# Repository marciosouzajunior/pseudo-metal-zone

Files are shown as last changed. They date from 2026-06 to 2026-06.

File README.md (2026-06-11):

# Pseudo Metal Zone

Pedal de distorção/fuzz pesado baseado em **RC4558/JRC4558**, desenvolvido em protoboard e depois convertido para **PCB V1 em KiCad**.

A ideia é chegar em uma distorção agressiva para baixo/guitarra, inspirada de forma conceitual no Boss Metal Zone e em timbres de hard rock/nu metal, mas com um circuito simples, compreendido estágio por estágio, usando componentes THT e um único CI dual op-amp.

## Objetivo sonoro

- Distorção pesada para baixo/guitarra.
- Mais definida que fuzz puro.
- Grave presente, mas sem embolar demais.
- Agudos controlados, reduzindo fizz/chiado.
- Funcionamento com alimentação simples de 9 V.
- Projeto didático, fácil de modificar e medir.

## Arquitetura do circuito

Fluxo geral do sinal:

```text
INPUT
→ C_INPUT_COUPLING
→ GAIN STAGE A
→ C_INTERSTAGE
→ GAIN STAGE B
→ C_CLIP_IN
→ ASYMMETRICAL CLIPPING
→ ANTI-FIZZ
→ MASTER VOLUME
→ C_OUTPUT_COUPLING
→ OUTPUT
```

## Alimentação e referência

### Alimentação

```text
Jack DC 9 V → chave SPST → +9V
```

- Fonte: 9 V DC.
- CI: RC4558/JRC4558.
- Pino 8 do 4558: +9 V.
- Pino 4 do 4558: GND.
- O circuito usa alimentação simples, então os estágios de áudio trabalham referenciados em VREF.

### Filtro principal

```text
+9V → C_POWER_FILTER 100uF → GND
```

Função: reduzir ruído/ripple da alimentação e estabilizar a linha de 9 V.

### VREF

```text
+9V
→ R_VREF_TOP 100k
→ VREF
→ R_VREF_BOTTOM 100k
→ GND
```

```text
VREF → C_VREF_FILTER 100uF → GND
```

- VREF esperado: aproximadamente 4,5 V.
- Inicialmente foi usado 1000 uF no VREF; funcionou, mas demorava mais para estabilizar e o áudio demorava a aparecer ao ligar.
- Valor atual escolhido: **100 uF**.

### Desacoplamento do op-amp

```text
pino 8 → C_OPAMP_DECOUPLING 100nF (104) → pino 4
```

Deve ficar fisicamente o mais próximo possível do RC4558.

## Entrada

```text
INPUT → C_INPUT_COUPLING 100nF (104) → pino 3
pino 3 → R_INPUT_BIAS 1M → VREF
```

Funções:

- `C_INPUT_COUPLING`: bloqueia DC e deixa o áudio passar.
- `R_INPUT_BIAS`: polariza a entrada em VREF e mantém alta impedância.

## Estágio A

Primeiro estágio de ganho, usando a primeira metade do 4558.

```text
pino 1 → R_STAGE1_GAIN 100k → pino 2
pino 2 → R_STAGE1_REF 4.7k → VREF
```

Onde:

- `R_STAGE1_GAIN` (100k): resistor de realimentação (feedback).
- `R_STAGE1_REF` (4.7k): resistor de referência que define o ganho junto com R_STAGE1_GAIN.

Ganho aproximado:

```text
R_STAGE1_GAIN / R_STAGE1_REF = 100k / 4.7k ≈ 22x
```

Função:

- Pré-amplificar o sinal.
- Preparar o sinal para o segundo estágio.
- Gerar drive inicial sem deixar o circuito totalmente fora de controle.

## Filtro entre estágios

```text
pino 1 → C_INTERSTAGE → pino 5
pino 5 → R_STAGE2_BIAS 100k → VREF
```

Valor escolhido:

```text
C_INTERSTAGE = 10nF (103)
```

Essa foi uma das mudanças mais importantes do projeto. O 103 cortou parte dos graves antes do segundo estágio, deixando o som mais definido e agressivo. O 104 ficou mais cheio/aberto, mas menos controlado. O 153 ficou no meio do caminho.

## Estágio B

Estágio principal de ganho, usando a segunda metade do 4558.

```text
pino 7 ↔ P_GAIN 100k ↔ pino 6
pino 6 → R_STAGE2_REF 22k → VREF
R_LIMIT_GAIN 47k em paralelo com P_GAIN
```

Ligação robusta sugerida do pot como reostato:

```text
terminal 2 e 3 unidos
terminal 1 no pino 6
```

O resistor `R_LIMIT_GAIN` em paralelo com o potenciômetro limita o ganho máximo e evita que a onda colapse ou fique irregular demais. Foram testados 22k e 47k; ambos funcionaram, com preferência atual por **47k**.

## Pré-clipping

```text
pino 7 → C_CLIP_IN → CLIP_NODE
```

Valor atual:

```text
C_CLIP_IN = 220nF (224 ou u22)
```

Função:

- Moldar o corpo do sinal antes dos diodos.
- Controlar quanto grave chega ao clipping.

Testes mostraram que 224 trouxe mais corpo e graves do que 104, mantendo uma resposta ainda utilizável.

## Clipping assimétrico

Configuração atual:

```text
CLIP_NODE
├─ 1 diodo 1N4148 para GND em um sentido
└─ 2 diodos 1N4148 em série para GND no sentido oposto
```

Função:

- Gerar a distorção principal.
- Produzir clipping assimétrico.
- Criar harmônicos mais ricos que a clipagem perfeitamente simétrica.

Comparações feitas:

- Sem diodos: o op-amp clipa por saturação em ganho alto, mas o resultado depende muito do nível de entrada.
- 2 diodos antiparalelos: clipping simétrico, visível e funcional.
- 3 diodos assimétricos: resultado favorito, mais interessante e menos “reto”.

## Anti-fizz

```text
CLIP_NODE → R_FIZZ 10k → OUTPUT_FILTER
OUTPUT_FILTER → C_FIZZ 3n3 → GND
```

Função:

- Reduzir agudos ásperos depois do clipping.
- Controlar fizz/chiado.
- Suavizar frequências altas sem matar totalmente a definição.

Configuração atual:

```text
R_FIZZ = 10k
C_FIZZ = 3n3
```

## Volume master e saída

```text
OUTPUT_FILTER → P_VOLUME 100k → C_OUTPUT_COUPLING 1uF → OUTPUT
```

Ligação típica do volume:

```text
terminal 1 = sinal
terminal 3 = GND
terminal 2 = saída
```

`C_OUTPUT_COUPLING = 1uF` foi mantido na V1 para bloquear DC residual antes do jack de saída.

## Indicação e proteção

### LED de indicação de energia

```text
+9V → R_LED 2.2k → LED_POWER → GND
```

Função:

- Indicar que o pedal está ligado.
- Proteger o LED com resistor limitador de corrente.

Valor do resistor:

- `R_LED = 2.2k` para LED típico de 5 mm com corrente limitada.
- LED escolhido: 5 mm THT, cor livre (vermelho recomendado).

## Configuração atual da PCB V1

| Bloco | Referência | Valor atual |
|---|---|---|
| **Fonte e referência** | | |
| CI principal | U1 | RC4558/JRC4558 DIP-8 + soquete |
| Alimentação | — | 9 V DC |
| Filtro de alimentação | C_POWER_FILTER | 100uF eletrolítico |
| VREF divisor | R_VREF_TOP / R_VREF_BOTTOM | 100k / 100k |
| Filtro VREF | C_VREF_FILTER | 100uF eletrolítico |
| Desacoplamento CI | C_OPAMP_DECOUPLING | 100nF (104) cerâmico |
| **Entrada** | | |
| Acoplamento entrada | C_INPUT_COUPLING | 100nF (104) filme P5mm |
| Bias entrada | R_INPUT_BIAS | 1M |
| **Estágio A** | | |
| Realimentação | R_STAGE1_GAIN | 100k |
| Referência | R_STAGE1_REF | 4.7k |
| **Interstage** | | |
| Filtro interstage | C_INTERSTAGE | 10nF (103) filme P5mm |
| Bias estágio B | R_STAGE2_BIAS | 100k |
| **Estágio B** | | |
| Ganho | P_GAIN | 100k potenciômetro linear |
| Limitador ganho | R_LIMIT_GAIN | 47k em paralelo com P_GAIN |
| Referência | R_STAGE2_REF | 22k |
| **Clipping** | | |
| Pré-clipping | C_CLIP_IN | 220nF (224) filme P5mm |
| Diodos clipping | D_CLIP_A, D_CLIP_B, D_CLIP_C | 3x 1N4148 assimétricos |
| **Anti-fizz** | | |
| Resistor anti-fizz | R_FIZZ | 10k |
| Capacitor anti-fizz | C_FIZZ | 3.3nF (3n3) filme P5mm |
| **Volume e saída** | | |
| Volume master | P_VOLUME | 100k potenciômetro log |
| Acoplamento saída | C_OUTPUT_COUPLING | 1uF eletrolítico |
| **Indicação** | | |
| LED indicador | LED_POWER | 5mm THT |
| Resistor LED | R_LED | 2.2k |

## Conectividade externa

A PCB V1 usa **headers e fios** para conexão de componentes externos:

- **DC_IN**: entrada de alimentação (9V DC) com chave.
- **INPUT**: jack de entrada de áudio.
- **OUTPUT**: jack de saída de áudio.
- **P_GAIN**: potenciômetro de ganho do estágio B (100k linear).
- **P_VOLUME**: potenciômetro de volume master (100k logarítmico).
- **Pads opcionais**: diversos pads de teste e pontos de modificação (13 pads 1x01).

Vide `docs/BOM.md` para detalhes de footprints e conexões.

## Principais descobertas

- Dois estágios funcionaram melhor que um único estágio.
- Ganho excessivo gera fuzz, compressão e perda de definição.
- O filtro entre estágios foi a alteração mais importante para definição.
- O anti-fizz reduziu significativamente o chiado/fizz dos agudos.
- Três diodos assimétricos soaram melhor que dois diodos simétricos.
- O sweet spot do ganho ficou baixo, aproximadamente entre 20% e 35% do pot em alguns testes.
- Abrir demais o ganho não significa necessariamente som melhor; em alguns pontos a onda fica irregular e a medição cai por compressão/limitação.
- O celular em 50% gera sinal mais forte e mais previsível que o baixo, então é bom para comparar medições, mas o instrumento real continua sendo a referência sonora final.
- O RC4558 sozinho consegue clipar por saturação quando há ganho suficiente.
- O TL072 foi testado, mas não trouxe vantagem imediata nesta fase.

## Resumo das medições principais

As medições completas estão em [docs/MEASUREMENTS.md](docs/MEASUREMENTS.md).

### Filtro entre estágios

Configuração:

```text
pino 1 → capacitor → pino 5
pino 5 → 100k → VREF
```

| Capacitor | 80 Hz | 120 Hz | 220 Hz | 440 Hz | 880 Hz | Resultado |
|---|---:|---:|---:|---:|---:|---|
| 104 | 0.0982 | 0.1110 | 0.1185 | 0.0876 | 0.0842 | mais grave/aberto |
| 153 | 0.0613 | 0.0852 | 0.1073 | 0.0851 | 0.0834 | intermediário |
| 103 | 0.0470 | 0.0687 | 0.0942 | 0.0804 | 0.0817 | escolhido, mais definido |

### Pré-clipping 104 vs 224

| C_CLIP_IN | 80 Hz | 120 Hz | 220 Hz | 440 Hz | 880 Hz | 2 kHz | 4 kHz | 8 kHz |
|---|---:|---:|---:|---:|---:|---:|---:|---:|
| 104 / 100nF | 0.079 | 0.091 | 0.103 | 0.102 | 0.105 | 0.098 | 0.075 | 0.053 |
| 224 / 220nF | 0.092 | 0.104 | 0.115 | 0.114 | 0.116 | 0.108 | 0.090 | 0.069 |

Resultado: **224** trouxe mais corpo e graves.

### Anti-fizz 10k + 3n3

| Frequência | Medição |
|---:|---:|
| 80 Hz | 0.086 |
| 120 Hz | 0.097 |
| 220 Hz | 0.114 |
| 440 Hz | 0.110 |
| 880 Hz | 0.114 |
| 2 kHz | 0.108 |
| 4 kHz | 0.091 |
| 8 kHz | 0.069 |

### Curva de ganho

| Potenciômetro | Medição | Observação |
|---:|---:|---|
| 0% | 0.069 | limpo |
| 25% | 0.097 | melhor ponto |
| 50% | 0.090 | deformação |
| 75% | 0.080 | irregular |
| 100% | 0.078 | irregular |

Sweet spot observado: **20% a 35%**.

## Notas resumidas de PCB

A PCB V1 foi pensada como placa experimental de face simples/THT, com alguns pontos de modificação.

- Camadas: 1.
- Dimensão aproximada: 62,65 mm × 61,8 mm.
- O silk fica do lado dos componentes.
- Jumpers podem cruzar trilhas, mas devem ser feitos com fio isolado quando passarem por cima de cobre/trilhas.
- Jumpers no lado dos componentes não devem encostar em trilhas expostas.
- Conferir especialmente jumpers que cruzam VREF, +9V ou saídas de estágio.

### Estratégia de layout

Fluxo recomendado:

```text
INPUT → STAGE A → STAGE B → CLIP → ANTI-FIZZ → VOLUME → OUTPUT
```

Prioridades:

- RC4558 central.
- Capacitor de desacoplamento o mais perto possível do CI.
- Alimentação e VREF estáveis.
- Entrada longe da saída e de nós de alto ganho.
- Trilhas curtas nos pontos de maior ganho.
- Plano de GND quando possível.
- Evitar laços grandes.
- Conferir orientação dos diodos.
- Conferir pinos do 4558 antes de soldar.

### Footprints usados/planejados

| Componente | Footprint |
|---|---|
| RC4558 | `Package_DIP:DIP-8_W7.62mm` |
| Resistores | `R_Axial_DIN0207_P7.62mm` |
| Diodos | `D_DO35_SOD27_P7.62mm` |
| Capacitores de voicing | `C_Rect_L7.2mm_W2.5mm_P5.00mm` |
| Eletrolíticos | `CP_Radial_D5.0mm_P2.00mm` |
| Potenciômetros | Header 1x3, ligados por fios |
| Jacks | Header 1x2, ligados por fios |

### Pontos úteis de modificação/teste

- `C_INTERSTAGE`: 103 (10nF), 153 (15nF), 104 (100nF).
- `C_CLIP_IN`: 104 (100nF), 224 (220nF).
- `R_LIMIT_GAIN`: 22k, 33k, 47k, 68k.
- `C_FIZZ`: sem capacitor, 2n2 (2.2nF), 3n3 (3.3nF), 4n7 (4.7nF), 6n8 (6.8nF).
- Pads de teste para +9V, GND, VREF, saída do estágio A, entrada do estágio B, CLIP_NODE e OUTPUT.

## Arquivos do repo

```text
README.md                         documentação principal

docs/
  BOM.md                          lista de componentes da PCB V1
  MEASUREMENTS.md                 medições e testes de desenvolvimento
  PseudoMetalZone_V1_Schematic.pdf
                                  esquemático exportado em PDF
  maloyk.png                      imagem de referência/inspiração

hardware/
  PseudoMetalZone_V1.kicad_sch    esquemático do KiCad
  PseudoMetalZone_V1.kicad_pcb    layout da PCB
  PseudoMetalZone_V1.kicad_pro    arquivo do projeto
  PseudoMetalZone_V1.kicad_prl    preferências do projeto

gerbers/
  PseudoMetalZone_V1-F_Cu.gtl     cobre frente
  PseudoMetalZone_V1-B_Cu.gbl     cobre verso
  PseudoMetalZone_V1-F_Mask.gts   máscara de solda frente
  PseudoMetalZone_V1-B_Mask.gbs   máscara de solda verso
  PseudoMetalZone_V1-F_Silkscreen.gto
                                  serigrafia frente
  PseudoMetalZone_V1-B_Silkscreen.gbo
                                  serigrafia verso
  PseudoMetalZone_V1-Edge_Cuts.gm1
                                  contorno da placa
  PseudoMetalZone_V1.drl          furos (drill)
  PseudoMetalZone_V1-job.gbrjob   configuração do job
```

## Procedimentos para nova placa

1. Conferir continuidade de +9V, GND e VREF antes de inserir o CI.
2. Alimentar a placa sem o 4558 e medir:
   - +9V no pino 8 do soquete.
   - GND no pino 4 do soquete.
   - VREF próximo de 4,5 V.
3. Conferir se não há curto entre +9V e GND.
4. Inserir o 4558 no soquete.
5. Testar áudio limpo em ganho baixo.
6. Testar ganho progressivamente.
7. Medir saída do estágio A, entrada do estágio B, CLIP_NODE e saída final.
8. Testar com guitarra real e baixo real antes de decidir novas alterações.

## Decisões a serem avaliadas depois

- Se o 224 antes dos diodos será mantido definitivamente.
- Se o anti-fizz 3n3 está no ponto ideal.
- Se o resistor de limite de ganho fica em 47k ou outro valor.
- Se o pedal precisa de tone control mais elaborado.
- Se o volume master e o capacitor de saída estão com valores ideais.
- Se vale comparar novamente 4558 vs TL072 na PCB.

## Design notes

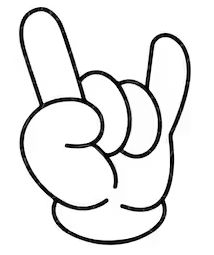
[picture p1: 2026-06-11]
docs/maloyk.png

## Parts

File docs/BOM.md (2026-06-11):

# BOM — Pseudo Metal Zone V1

Arquivo consolidado para compra e conferência de componentes da PCB V1.

> **Objetivo**: evitar compra de componente com footprint/tamanho errado.  
> **Placa**: THT (through-hole) com potenciômetros, jacks e chave ligados por headers/fios.  
> **Referência completa**: ver [README.md](../README.md) para especificações e valores.

---

## Busca rápida por bloco funcional

Para encontrar componentes de uma seção específica do circuito, consulte:

| Bloco | Componentes | Seção do BOM |
|---|---|---|
| Alimentação e VREF | U1, C_POWER_FILTER, C_VREF_FILTER, R_VREF_TOP/BOTTOM, C_OPAMP_DECOUPLING | Resistores, Capacitores eletrolíticos |
| Entrada | C_INPUT_COUPLING, R_INPUT_BIAS | Capacitores filme, Resistores |
| Estágio A | R_STAGE1_GAIN, R_STAGE1_REF | Resistores |
| Interstage | C_INTERSTAGE, R_STAGE2_BIAS | Capacitores filme, Resistores |
| Estágio B (ganho) | P_GAIN, R_LIMIT_GAIN, R_STAGE2_REF | Potenciômetros, Resistores |
| Clipping | C_CLIP_IN, D_CLIP_A/B/C | Capacitores filme, Diodos |
| Anti-fizz | R_FIZZ, C_FIZZ | Resistores, Capacitores filme |
| Volume e saída | P_VOLUME, C_OUTPUT_COUPLING | Potenciômetros, Capacitores eletrolíticos |
| Indicação | LED_POWER, R_LED | LED, Resistores |

---

## Resumo crítico de tamanhos

| Categoria | Footprint na PCB | Comprar como |
|---|---|---|
| Resistores | `R_Axial_DIN0207_L6.3mm_D2.5mm_P7.62mm_Horizontal` | Resistor axial THT 1/4W, corpo ~6.3 mm, passo 7.62 mm |
| Diodos | `D_DO-35_SOD27_P7.62mm_Horizontal` | 1N4148 axial THT DO-35, vidro, passo 7.62 mm |
| CI | `DIP-8_W7.62mm` | RC4558 / JRC4558 DIP-8 + soquete DIP-8 |
| Capacitores de voicing | `C_Rect_L7.2mm_W2.5mm_P5.00mm` | Filme/poliéster box THT, passo 5 mm, 50V/63V/100V |
| Desacoplamento opamp | `C_Disc_D5.0mm_W2.5mm_P2.50mm` | Cerâmico disco ou MLCC radial 100nF, passo 2.5 mm |
| Eletrolíticos | `CP_Radial_D5.0mm_P2.00mm` | Eletrolítico radial THT, diâmetro 5 mm, passo 2 mm |
| LED | `LED_D5.0mm` | LED 5 mm THT |
| Pots externos | `PinHeader_1x03_P2.54mm` | Potenciômetros de painel ligados por fio |
| Jacks/chave externos | `PinHeader_1x02_P2.54mm` | Jacks/chave ligados por fio |
| Pads/testes/jumpers | `PinHeader_1x01_P2.54mm` | Header opcional ou fio/perninha de resistor |

---

## Lista de compra recomendada

### CI e soquete

| Item | Valor/modelo | Qtde | Comprar como | Observações |
|---|---:|---:|---|---|
| U1 | RC4558 / JRC4558 | 1 | CI DIP-8 THT | Evitar SMD/SOIC |
| Soquete U1 | DIP-8 | 1 | Soquete DIP-8, comum ou torneado | Recomendado para troca/teste |

### Resistores

Comprar todos como **resistores axiais THT 1/4W**, preferencialmente metal film 1%. Carbono 5% também funciona.

| Referência | Valor | Qtde | Footprint | Comprar como | Observações |
|---|---:|---:|---|---|---|
| R_INPUT_BIAS1 | 1M | 1 | DIN0207 P7.62 | 1M 1/4W axial | Bias da entrada para VREF |
| R_STAGE1_GAIN1, R_STAGE2_BIAS1, R_VREF_BOTTOM1, R_VREF_TOP1 | 100k | 4 | DIN0207 P7.62 | 100k 1/4W axial | Feedback estágio A, bias estágio B e divisor VREF |
| R_LIMIT_GAIN1 | 47k | 1 | DIN0207 P7.62 | 47k 1/4W axial | Em paralelo ao gain; evita colapso/saturação excessiva |
| R_STAGE2_REF1 | 22k | 1 | DIN0207 P7.62 | 22k 1/4W axial | Referência do estágio B |
| R_FIZZ1 | 10k | 1 | DIN0207 P7.62 | 10k 1/4W axial | Anti-fizz |
| R_STAGE1_REF1 | 4.7k | 1 | DIN0207 P7.62 | 4k7 1/4W axial | Define ganho do estágio A com 100k |
| R_LED1 | 2k2 | 1 | DIN0207 P7.62 | 2k2 1/4W axial | Limitador do LED |

**Total de resistores:** 10 unidades.

### Diodos

| Referência | Valor/modelo | Qtde | Footprint | Comprar como | Observações |
|---|---:|---:|---|---|---|
| D_CLIP_A1, D_CLIP_B1, D_CLIP_C1 | 1N4148 | 3 | DO-35 P7.62 | 1N4148 axial THT de vidro | Clipping assimétrico; não comprar SMD |

### Capacitores de filme / poliéster / box

Comprar como **capacitor filme/poliéster box THT com passo 5 mm**. Tensão de 50V, 63V ou 100V é suficiente para pedal de 9V.

**Nota sobre códigos comuns**: o código de três dígitos indica o valor em pF (exemplo: 104 = 100nF, 103 = 10nF). Este é o código impresso no capacitor.

| Referência | Valor | Código comum | Qtde | Footprint | Comprar como | Observações |
|---|---:|---|---:|---|---|---|
| C_INPUT_COUPLING1 | 100nF | 104 | 1 | Rect L7.2 W2.5 P5.00 | Filme box 100nF P5mm | Acoplamento de entrada |
| C_INTERSTAGE1 | 10nF | 103 | 1 | Rect L7.2 W2.5 P5.00 | Filme box 10nF P5mm | Filtro entre estágios; valor escolhido para timbre mais definido |
| C_CLIP_IN1 | 220nF | 224 / u22 | 1 | Rect L7.2 W2.5 P5.00 | Filme box 220nF P5mm | Pré-clipping; mais corpo/graves que 100nF |
| C_FIZZ1 | 3.3nF | 3n3 / 332 | 1 | Rect L7.2 W2.5 P5.00 | Filme box 3.3nF P5mm | Anti-fizz |

**Atenção:** evitar capacitores grandes de 250V com passo 10 mm, 15 mm ou 22.5 mm. Eles podem até funcionar eletricamente, mas provavelmente não encaixam bem na PCB.

### Capacitor de desacoplamento do opamp

| Referência | Valor | Código comum | Qtde | Footprint | Comprar como | Observações |
|---|---:|---|---:|---|---|---|
| C_OPAMP_DECOUPLING1 | 100nF | 104 | 1 | Disc D5 W2.5 P2.50 | Cerâmico disco 100nF P2.5mm | Deve ficar próximo do RC4558, entre pino 8 e pino 4 |

### Capacitores eletrolíticos

Comprar como **eletrolítico radial THT, diâmetro 5 mm, passo 2 mm**.

| Referência | Valor | Qtde | Footprint | Comprar como | Observações |
|---|---:|---:|---|---|---|
| C_OUTPUT_COUPLING1 | 1uF | 1 | CP Radial D5 P2.00 | 1uF 16V ou 25V radial D5/P2 | Saída; bloqueia DC residual |
| C_POWER_FILTER1, C_VREF_FILTER1 | 100uF | 2 | CP Radial D5 P2.00 | 100uF 16V radial D5/P2 | Filtro alimentação e VREF |

**Atenção:** 100uF 25V pode servir se o corpo for D5mm. 100uF 50V geralmente é maior e deve ser evitado. Procurar por `100uF 16V 5x11mm radial P2mm`.

### LED

| Referência | Valor/modelo | Qtde | Footprint | Comprar como | Observações |
|---|---:|---:|---|---|---|
| LED_POWER1 | LED | 1 | LED_D5.0mm | LED 5mm THT | Cor livre; respeitar polaridade |

### Potenciômetros externos

Na PCB, os potenciômetros são conectados por **headers 1x03 P2.54mm**. Eles não são soldados diretamente como potenciômetros PCB-mount.

| Referência | Valor | Qtde | Footprint na PCB | Comprar como | Recomendação |
|---|---:|---:|---|---|---|
| P_GAIN1 | 100k | 1 | Header 1x03 P2.54 | Potenciômetro de painel B100k linear | Ligado por fios; usado como reostato |
| P_VOLUME1 | 100k | 1 | Header 1x03 P2.54 | Potenciômetro de painel A100k log/audio | B100k funciona, mas A100k é mais natural para volume |

### Headers, pads, jacks e chave

A PCB usa headers de 2.54 mm para conexões externas, pads de teste e jumpers.

| Referência | Qtde no BOM | Footprint | Comprar como | Observações |
|---|---:|---|---|---|
| Pads 1x01 diversos | 13 | PinHeader 1x01 P2.54 | Barra de pinos macho 2.54mm ou deixar sem montar | Muitos são pontos de teste/modificação opcionais |
| DC_IN1 | 1 | PinHeader 1x02 P2.54 | Header 1x02 ou fio direto | Entrada/chave de alimentação conforme montagem |
| INPUT1, OUTPUT1, POWER_SW1 | 3 | PinHeader 1x02 P2.54 | Header 1x02 ou fio direto | Jacks/chave externos ligados por fio |
| P_GAIN1, P_VOLUME1 | 2 | PinHeader 1x03 P2.54 | Header 1x03 | Para ligação dos potenciômetros |
| Jumpers | conforme PCB | Pads/headers | Fio rígido ou perninha de resistor | Não precisa comprar componente especial |

---

## Componentes opcionais/extras recomendados para voicing

Esses valores ajudam nos testes futuros, caso a V1 precise de ajuste após testar com guitarra real.

| Ponto | Valor atual | Extras úteis | Efeito esperado |
|---|---:|---|---|
| C_INTERSTAGE | 10nF | 15nF, 100nF | 10nF = mais tight/definido; 100nF = mais grave/aberto |
| C_CLIP_IN | 220nF | 100nF | 220nF = mais corpo/graves; 100nF = mais tight |
| R_LIMIT_GAIN | 47k | 22k, 33k, 68k | Ajusta limite do ganho máximo |
| C_FIZZ | 3.3nF | 2.2nF, 4.7nF, 6.8nF | Ajusta corte de agudos/fizz |

---

## O que evitar comprar errado

- RC4558 / 4558 em SMD/SOIC.
- 1N4148 SMD.
- Resistores 1/2W grandes, se quiser montagem limpa.
- Capacitor 220nF 250V grande com passo 15mm.
- Capacitor 100nF/10nF/3n3 com passo 10mm ou 15mm para os pontos de voicing.
- Eletrolítico 100uF 50V grande.
- Potenciômetro PCB-mount esperando encaixar direto na placa.

---

## BOM original agrupado por referência

| Reference | Qty | Value | Footprint | Nota de compra |
|---|---:|---|---|---|
| 9V_PAD1, CLIP_NODE_PAD1, GND_PAD1, GND_PAD2, JMP_9V_A1, JMP_9V_B1, JMP_INTER_A1, JMP_INTER_B1, OUTPUT_PAD1, STAGE1_OUT_PAD1, STAGE2_IN_PAD1, VREF_PAD1, VREF_PAD2 | 13 | Conn_01x01 | PinHeader_1x01_P2.54mm_Vertical | Opcional; pads de teste/jumpers/mods |
| C_CLIP_IN1 | 1 | 220nF | C_Rect_L7.2mm_W2.5mm_P5.00mm | Filme box P5mm, evitar 250V grande |
| C_FIZZ1 | 1 | 3n3 | C_Rect_L7.2mm_W2.5mm_P5.00mm | Filme box P5mm |
| C_INPUT_COUPLING1 | 1 | 100nF | C_Rect_L7.2mm_W2.5mm_P5.00mm | Filme box P5mm |
| C_INTERSTAGE1 | 1 | 10nF | C_Rect_L7.2mm_W2.5mm_P5.00mm | Filme box P5mm |
| C_OPAMP_DECOUPLING1 | 1 | 100nF | C_Disc_D5.0mm_W2.5mm_P2.50mm | Cerâmico P2.5mm |
| C_OUTPUT_COUPLING1 | 1 | 1uF | CP_Radial_D5.0mm_P2.00mm | Eletrolítico radial D5/P2 |
| C_POWER_FILTER1, C_VREF_FILTER1 | 2 | 100uF | CP_Radial_D5.0mm_P2.00mm | Eletrolítico radial D5/P2, preferir 16V 5x11mm |
| DC_IN1 | 1 | POWER_SW | PinHeader_1x02_P2.54mm_Vertical | Header/fio para alimentação |
| D_CLIP_A1, D_CLIP_B1, D_CLIP_C1 | 3 | 1N4148 | D_DO-35_SOD27_P7.62mm_Horizontal | 1N4148 axial THT vidro |
| INPUT1, OUTPUT1, POWER_SW1 | 3 | — | PinHeader_1x02_P2.54mm_Vertical | Jacks/chave por fio |
| LED_POWER1 | 1 | LED | LED_D5.0mm | LED 5mm THT |
| P_GAIN1, P_VOLUME1 | 2 | 100k | PinHeader_1x03_P2.54mm_Vertical | Pots externos por fio; B100k gain, A100k volume |
| R_FIZZ1 | 1 | 10k | R_Axial_DIN0207_L6.3mm_D2.5mm_P7.62mm | 1/4W axial |
| R_INPUT_BIAS1 | 1 | 1M | R_Axial_DIN0207_L6.3mm_D2.5mm_P7.62mm | 1/4W axial |
| R_LED1 | 1 | 2k2 | R_Axial_DIN0207_L6.3mm_D2.5mm_P7.62mm | 1/4W axial |
| R_LIMIT_GAIN1 | 1 | 47k | R_Axial_DIN0207_L6.3mm_D2.5mm_P7.62mm | 1/4W axial |
| R_STAGE1_GAIN1, R_STAGE2_BIAS1, R_VREF_BOTTOM1, R_VREF_TOP1 | 4 | 100k | R_Axial_DIN0207_L6.3mm_D2.5mm_P7.62mm | 1/4W axial |
| R_STAGE1_REF1 | 1 | 4.7k | R_Axial_DIN0207_L6.3mm_D2.5mm_P7.62mm | 1/4W axial |
| R_STAGE2_REF1 | 1 | 22k | R_Axial_DIN0207_L6.3mm_D2.5mm_P7.62mm | 1/4W axial |
| U1 | 1 | RC4558 | DIP-8_W7.62mm | CI DIP-8 + soquete recomendado |

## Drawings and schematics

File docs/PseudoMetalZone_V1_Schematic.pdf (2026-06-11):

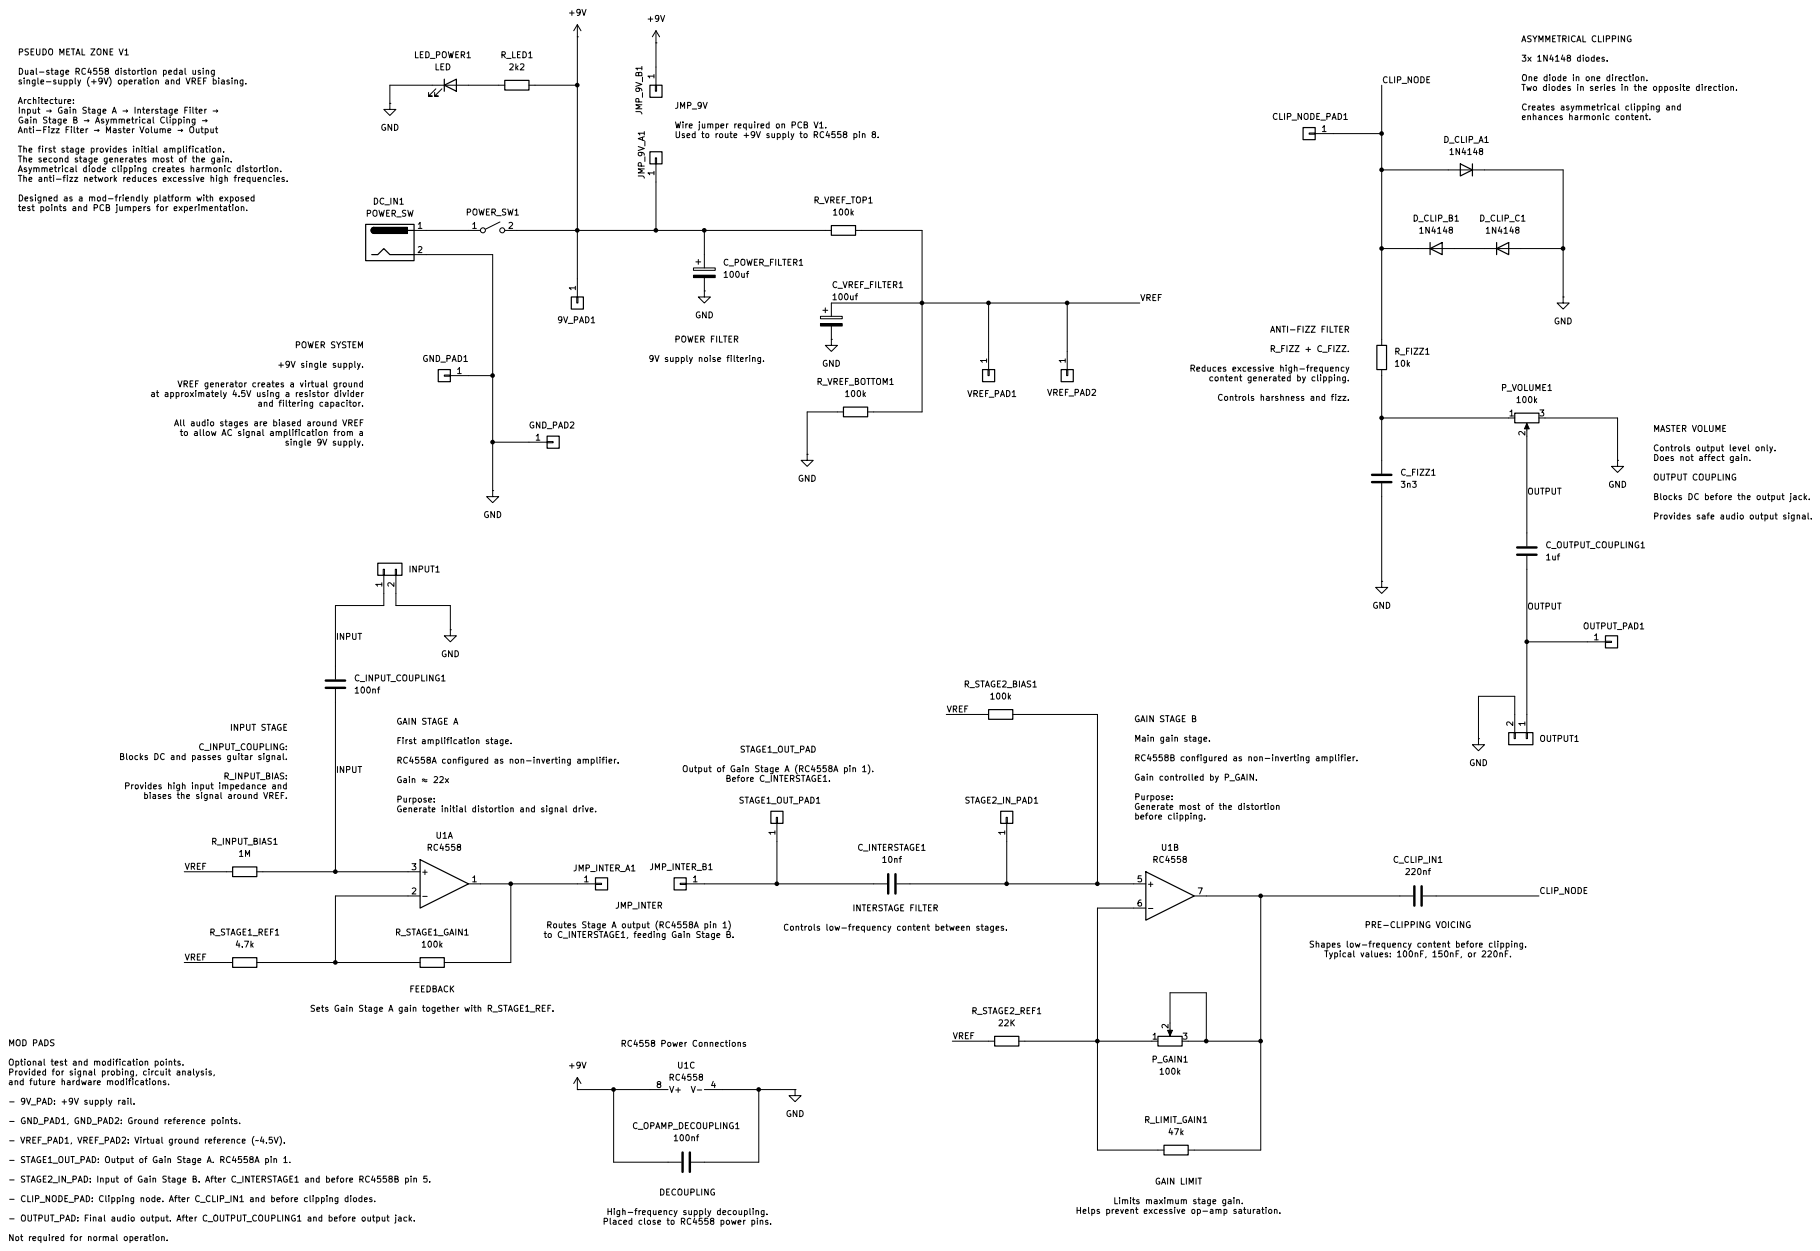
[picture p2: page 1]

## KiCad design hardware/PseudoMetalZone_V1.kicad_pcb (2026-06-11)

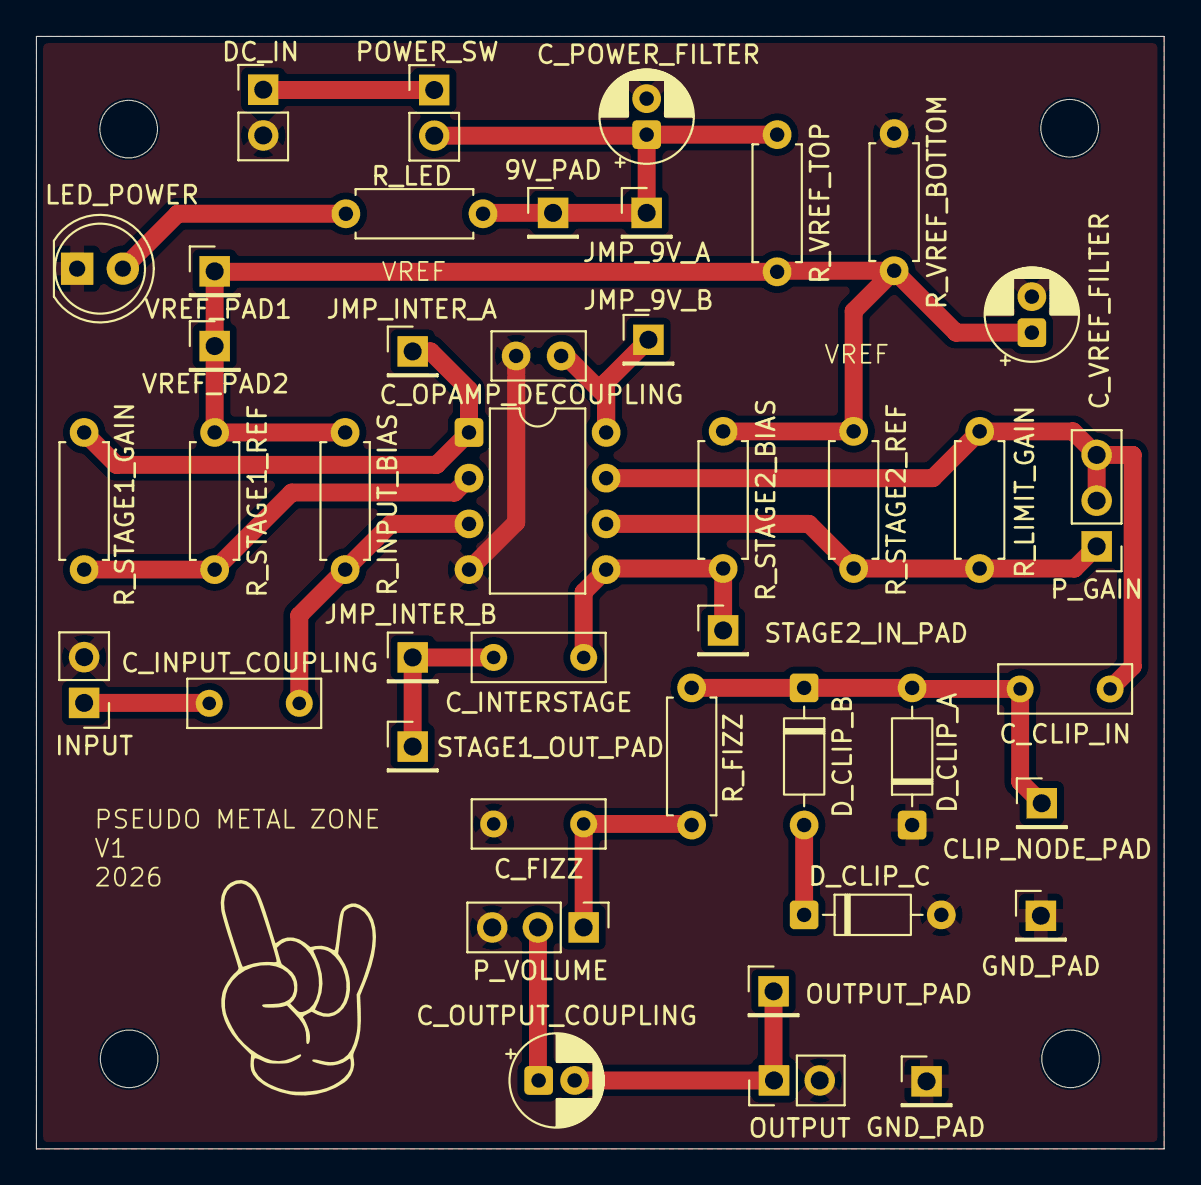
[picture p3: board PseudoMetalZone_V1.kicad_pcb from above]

Board: 2 copper layers, 62.7 x 61.8 mm, 42 parts (0 on the bottom side), 16 nets.

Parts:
9V_PAD: Conn_01x01; PinHeader_1x01_P2.54mm_Vertical
CLIP_NODE_PAD: Conn_01x01; PinHeader_1x01_P2.54mm_Vertical
C_CLIP_IN: 220nf; C_Rect_L7.2mm_W2.5mm_P5.00mm
C_FIZZ: 3n3; C_Rect_L7.2mm_W2.5mm_P5.00mm
C_INPUT_COUPLING: 100nf; C_Rect_L7.2mm_W2.5mm_P5.00mm
C_INTERSTAGE: 10nf; C_Rect_L7.2mm_W2.5mm_P5.00mm
C_OPAMP_DECOUPLING: 100nf; C_Disc_D5.0mm_W2.5mm_P2.50mm
C_OUTPUT_COUPLING: 1uf; CP_Radial_D5.0mm_P2.00mm
C_POWER_FILTER: 100uf; CP_Radial_D5.0mm_P2.00mm
C_VREF_FILTER: 100uf; CP_Radial_D5.0mm_P2.00mm
DC_IN: POWER_SW; PinHeader_1x02_P2.54mm_Vertical
D_CLIP_A: 1N4148; D_DO-35_SOD27_P7.62mm_Horizontal
D_CLIP_B: 1N4148; D_DO-35_SOD27_P7.62mm_Horizontal
D_CLIP_C: 1N4148; D_DO-35_SOD27_P7.62mm_Horizontal
GND_PAD: Conn_01x01; PinHeader_1x01_P2.54mm_Vertical
GND_PAD#2: Conn_01x01; PinHeader_1x01_P2.54mm_Vertical
INPUT: PinHeader_1x02_P2.54mm_Vertical
JMP_9V_A, JMP_9V_B: Conn_01x01; PinHeader_1x01_P2.54mm_Vertical
JMP_INTER_A: Conn_01x01; PinHeader_1x01_P2.54mm_Vertical
JMP_INTER_B: Conn_01x01; PinHeader_1x01_P2.54mm_Vertical
LED_POWER: LED; LED_D5.0mm
OUTPUT: PinHeader_1x02_P2.54mm_Vertical
OUTPUT_PAD: Conn_01x01; PinHeader_1x01_P2.54mm_Vertical
POWER_SW: PinHeader_1x02_P2.54mm_Vertical
P_GAIN: 100k; PinHeader_1x03_P2.54mm_Vertical
P_VOLUME: 100k; PinHeader_1x03_P2.54mm_Vertical
R_FIZZ: 10k; R_Axial_DIN0207_L6.3mm_D2.5mm_P7.62mm_Horizontal
R_INPUT_BIAS: 1M; R_Axial_DIN0207_L6.3mm_D2.5mm_P7.62mm_Horizontal
R_LED: 2k2; R_Axial_DIN0207_L6.3mm_D2.5mm_P7.62mm_Horizontal
R_LIMIT_GAIN: 47k; R_Axial_DIN0207_L6.3mm_D2.5mm_P7.62mm_Horizontal
R_STAGE1_GAIN, R_STAGE2_BIAS: 100k; R_Axial_DIN0207_L6.3mm_D2.5mm_P7.62mm_Horizontal
R_STAGE1_REF: 4.7k; R_Axial_DIN0207_L6.3mm_D2.5mm_P7.62mm_Horizontal
R_STAGE2_REF: 22K; R_Axial_DIN0207_L6.3mm_D2.5mm_P7.62mm_Horizontal
R_VREF_BOTTOM: 100k; R_Axial_DIN0207_L6.3mm_D2.5mm_P7.62mm_Horizontal
R_VREF_TOP: 100k; R_Axial_DIN0207_L6.3mm_D2.5mm_P7.62mm_Horizontal
STAGE1_OUT_PAD, STAGE2_IN_PAD: Conn_01x01; PinHeader_1x01_P2.54mm_Vertical
U1: RC4558; DIP-8_W7.62mm
VREF_PAD1, VREF_PAD2: Conn_01x01; PinHeader_1x01_P2.54mm_Vertical

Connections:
+9V: 9V_PAD.1 (Pin_1_1), C_OPAMP_DECOUPLING.1, C_POWER_FILTER.1, JMP_9V_A.1 (Pin_1_1), JMP_9V_B.1 (Pin_1_1), POWER_SW.2 (B), R_LED.2, R_VREF_TOP.1, U1.8 (V+)
/CLIP_NODE: CLIP_NODE_PAD.1 (Pin_1_1), C_CLIP_IN.2, D_CLIP_A.2 (A), D_CLIP_B.1 (K), R_FIZZ.1
/INPUT: C_INPUT_COUPLING.1, C_INPUT_COUPLING.2, INPUT.1, R_INPUT_BIAS.2, U1.3 (+)
/OUTPUT: C_OUTPUT_COUPLING.1, C_OUTPUT_COUPLING.2, OUTPUT.1, OUTPUT_PAD.1 (Pin_1_1), P_VOLUME.2
/VREF: C_VREF_FILTER.1, R_INPUT_BIAS.1, R_STAGE1_REF.1, R_STAGE2_BIAS.1, R_STAGE2_REF.1, R_VREF_BOTTOM.2, R_VREF_TOP.2, VREF_PAD1.1 (Pin_1_1), VREF_PAD2.1 (Pin_1_1)
GND: C_FIZZ.2, C_OPAMP_DECOUPLING.2, C_POWER_FILTER.2, C_VREF_FILTER.2, DC_IN.2, D_CLIP_A.1 (K), D_CLIP_C.2 (A), GND_PAD.1 (Pin_1_1), GND_PAD#2.1 (Pin_1_1), INPUT.2, LED_POWER.1 (K), OUTPUT.2, P_VOLUME.3, R_VREF_BOTTOM.1, U1.4 (V-)
unnamed: C_CLIP_IN.1, P_GAIN.2, P_GAIN.3, R_LIMIT_GAIN.2, U1.7
unnamed: C_FIZZ.1, P_VOLUME.1, R_FIZZ.2
unnamed: D_CLIP_B.2 (A), D_CLIP_C.1 (K)
unnamed: JMP_INTER_A.1 (Pin_1_1), R_STAGE1_GAIN.2, U1.1
unnamed: C_INTERSTAGE.1, JMP_INTER_B.1 (Pin_1_1), STAGE1_OUT_PAD.1 (Pin_1_1)
unnamed: LED_POWER.2 (A), R_LED.1
unnamed: DC_IN.1, POWER_SW.1 (A)
unnamed: C_INTERSTAGE.2, R_STAGE2_BIAS.2, STAGE2_IN_PAD.1 (Pin_1_1), U1.5 (+)
unnamed: R_STAGE1_GAIN.1, R_STAGE1_REF.2, U1.2 (-)
unnamed: P_GAIN.1, R_LIMIT_GAIN.1, R_STAGE2_REF.2, U1.6 (-)

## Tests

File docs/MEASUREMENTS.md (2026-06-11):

# Medições e testes

Medições coletadas durante o desenvolvimento do Pseudo Metal Zone em protoboard e na preparação da PCB V1.

> **Leia primeiro**: [README.md](../README.md) para entender a arquitetura.  
> **Referência de componentes**: [BOM.md](BOM.md) para valores exatos e footprints.

---

## Ambiente geral de teste

- CI principal: RC4558/JRC4558.
- Alimentação: 9 V.
- VREF: aproximadamente 4,5 V.
- Sinal de teste: celular em aproximadamente 50% de volume, onda senoidal, principalmente 440 Hz.
- Instrumento real também testado: baixo.
- Ferramenta de visualização: Visual Analyser via entrada de áudio do computador.
- Saída medida sempre depois de capacitor de acoplamento, não diretamente no pino do op-amp.

## Testes iniciais de resistor de ganho para VREF

Configuração conceitual do estágio inicial:

```text
pino 1 → pot/feedback → pino 2
pino 2 → resistor → VREF
```

### 1k

Cores: marrom, preto, vermelho.

Com tom de 440 Hz:

| Pot | Medição aproximada |
|---:|---:|
| 50% | 0.203 V RMS |
| 100% | 0.357 V RMS |

Observações:

- Ganho muito alto.
- Clipping natural do op-amp a partir de aproximadamente 75% do pot.
- Com diodos, começa a clipar por volta de 25% do pot.
- Excelente para distorção pesada, mas com pouca faixa limpa.

### 2.2k

Cores: vermelho, vermelho, vermelho.

| Pot | Medição aproximada |
|---:|---:|
| 50% | 0.097 V RMS |
| 100% | 0.187 V RMS |

Observações:

- Melhor compromisso entre controle e ganho na fase inicial.
- Sem clipping natural tão significativo quanto 1k.

### 4.7k

Cores: amarelo, violeta, vermelho.

| Pot | Medição aproximada |
|---:|---:|
| 50% | 0.047 V RMS |
| 100% | 0.090 V RMS |

Observações:

- Som limpo.
- Ganho baixo para o objetivo de distorção pesada em estágio único.
- Acabou sendo usado no Estágio A da arquitetura de dois estágios.

### 10k

Cores: marrom, preto, laranja.

| Pot | Medição aproximada |
|---:|---:|
| 100% | 0.053 V RMS |

Observações:

- Muito limpo.
- Ganho insuficiente para a proposta como estágio principal de distorção.

## Teste com baixo real: 2.2k sem diodos

| Pot | Medição aproximada | Observação |
|---:|---:|---|
| 0% | 0.003 V | quase inaudível no computador |
| 50% | 0.05 V | audível e visível na onda |
| 100% | 0.10 V | mais alto, ainda controlado |

## Teste com baixo real: 2.2k + 2 diodos depois do 104

| Pot | Medição aproximada | Observação |
|---:|---:|---|
| 0% | 0.003 V | quase inaudível no computador |
| 50% | 0.05 V | audível, onda balançando e alguma distorção |
| 100% | 0.06 V | mais distorção, mas volume limitado |

Interpretação:

- Os diodos limitam o sinal.
- Ganho adicional vira compressão, harmônicos e distorção, não necessariamente mais volume.

## Clipping por saturação do op-amp

Sem diodos, o RC4558 também mostrou clipping quando o ganho ficou alto o suficiente.

Condição observada:

- Resistor de 1k.
- Pot acima de aproximadamente 75%.
- Senoide começa a achatar.

Conclusão:

- O 4558 sozinho consegue gerar distorção por saturação.
- Os diodos tornam o comportamento mais controlado e previsível.

## Clipping com diodos

### Um diodo

- Clipagem assimétrica.
- Difícil perceber em alguns testes.

### Dois diodos antiparalelos

- Clipagem simétrica.
- Claramente visível no osciloscópio.
- Funcional, mas menos interessante que a assimétrica com três diodos.

### Três diodos assimétricos

Configuração favorita:

```text
CLIP_NODE
├─ 1 diodo para GND em um sentido
└─ 2 diodos em série para GND no sentido oposto
```

Resultado:

- Mais interessante harmonicamente.
- Mais próximo do objetivo de distorção pesada, com menos sensação de clipagem “reta”.

## Filtro entre estágios

Configuração testada:

```text
pino 1 → capacitor → pino 5
pino 5 → 100k → VREF
```

| Capacitor | 80 Hz | 120 Hz | 220 Hz | 440 Hz | 880 Hz | Leitura subjetiva |
|---|---:|---:|---:|---:|---:|---|
| 104 / 100nF | 0.0982 | 0.1110 | 0.1185 | 0.0876 | 0.0842 | mais grave, mais aberto |
| 153 / 15nF | 0.0613 | 0.0852 | 0.1073 | 0.0851 | 0.0834 | intermediário |
| 103 / 10nF | 0.0470 | 0.0687 | 0.0942 | 0.0804 | 0.0817 | mais definido, escolhido |

Escolha atual: **103 / 10nF**.

## Pré-clipping: 104 vs 224

Configuração:

```text
pino 7 → C_CLIP_IN → CLIP_NODE
```

| C_CLIP_IN | 80 Hz | 120 Hz | 220 Hz | 440 Hz | 880 Hz | 2 kHz | 4 kHz | 8 kHz |
|---|---:|---:|---:|---:|---:|---:|---:|---:|
| 104 / 100nF | 0.079 | 0.091 | 0.103 | 0.102 | 0.105 | 0.098 | 0.075 | 0.053 |
| 224 / 220nF | 0.092 | 0.104 | 0.115 | 0.114 | 0.116 | 0.108 | 0.090 | 0.069 |

Resultado:

- 224 produz mais corpo e graves.
- 104 fica mais tight.
- Escolha atual da PCB V1: **224 / 220nF**.

## Anti-fizz

Configuração:

```text
CLIP_NODE → 10k → OUTPUT_FILTER
OUTPUT_FILTER → 3n3 → GND
```

| Frequência | Medição |
|---:|---:|
| 80 Hz | 0.086 |
| 120 Hz | 0.097 |
| 220 Hz | 0.114 |
| 440 Hz | 0.110 |
| 880 Hz | 0.114 |
| 2 kHz | 0.108 |
| 4 kHz | 0.091 |
| 8 kHz | 0.069 |

Resultado:

- Reduziu fizz/chiado dos agudos.
- Manteve definição suficiente.
- Configuração atual: **10k + 3n3**.

## Curva de ganho da configuração atual

| Potenciômetro | Medição | Observação |
|---:|---:|---|
| 0% | 0.069 | limpo |
| 25% | 0.097 | melhor ponto |
| 50% | 0.090 | deformação |
| 75% | 0.080 | irregular |
| 100% | 0.078 | irregular |

Sweet spot observado:

```text
20% a 35%
```

Interpretação:

- O ganho máximo não foi o melhor som.
- Acima de certo ponto há compressão, deformação e irregularidade.
- O resistor em paralelo no pot ajuda a evitar colapso da onda.

## Resistor em paralelo no pot de ganho

Testados:

| Valor | Resultado |
|---|---|
| 22k | funcionou, limitou ganho |
| 47k | funcionou, preferência atual |

Conclusão:

- Ambos evitaram colapso da onda.
- Diferença subjetiva pequena.
- PCB V1 usa **47k** como ponto inicial.

## FFT e harmônicos

Sem clipping:

- Pico dominante na frequência fundamental, por exemplo 440 Hz.

Com clipping:

- Surgem harmônicos.
- Exemplos observados/conceituais: 440 Hz, 1320 Hz, 2200 Hz, 3080 Hz.

Conclusão:

- A FFT confirmou que o clipping cria conteúdo harmônico adicional.
- O osciloscópio mostra o achatamento da onda, enquanto a FFT mostra o enriquecimento harmônico.

## Observações de teste

- O celular em 50% foi uma referência prática para comparação entre mudanças.
- O baixo real gera sinal diferente e deve ser usado para validação sonora final.
- Com áudio limpo de celular, havia pouca distorção abaixo de aproximadamente 75% em algumas configurações iniciais.
- Com diodos, o volume tende a limitar e o aumento de ganho vira mais distorção/compressão.
- O anti-fizz foi uma das mudanças mais úteis para reduzir aspereza.

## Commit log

2026-06-11 Atualiza documentação do README.md e do BOM.md com informações sobre a PCB V1 e melhorias na seção de medições.
2026-06-11 Remove temporary lock file and clear used designators in PCB project file
